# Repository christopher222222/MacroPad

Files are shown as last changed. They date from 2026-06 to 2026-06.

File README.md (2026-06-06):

# Full-Suite MacroPad
The Full-Suite MacroPad is a configurable macropad that incorporates Cherry MX key switches, a rotary encoder, and a 2" IPS screen that can display anything.
### Features

 - 2" IPS Display for displaying data and images (firmware support coming soon)
 - 12 Cherry MX Keyswitches
 - One Mechanical Rotary Encoder with Full Customization
 - 2000Mah Lipo Battery With Charging Circuit and Charge Sensing
 - Bluetooth Low Energy Wireless Connectivity With HID, Configuration, and Image Streaming Support (configuration and image streaming firmware support coming soon)
 - Full Low Latency NKRO (N-Key Rollover) Using MCP23017 I2C IO Expander
 - Optional Heatset Insets on the bottom of MacroPad for Custom Mounting

## CAD Model
This case uses an unconventional method of mounting by sliding from sides of the PCB to notches on the sides of the Front Case. After that, the case can now be fully assembled from 2 M3x5x4 heatset inserts and 2 M3x8 SHCS screws.
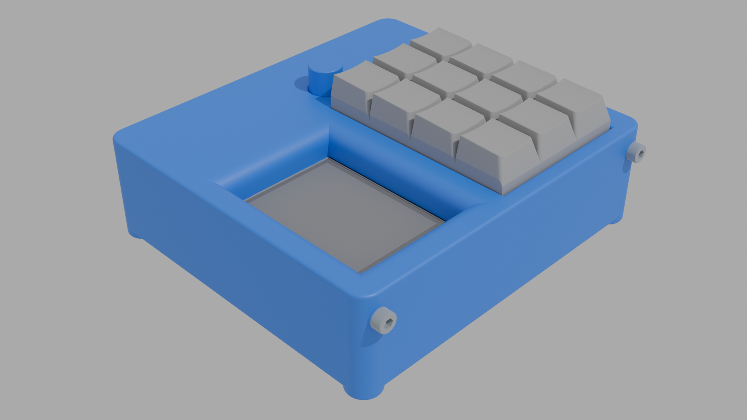
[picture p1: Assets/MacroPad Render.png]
MacroPad Render

Made in Onshape, Rendered in Blender.
## PCB and Schematic
The PCB and Schematic were both designed in EasyEDA Pro.
### Schematic
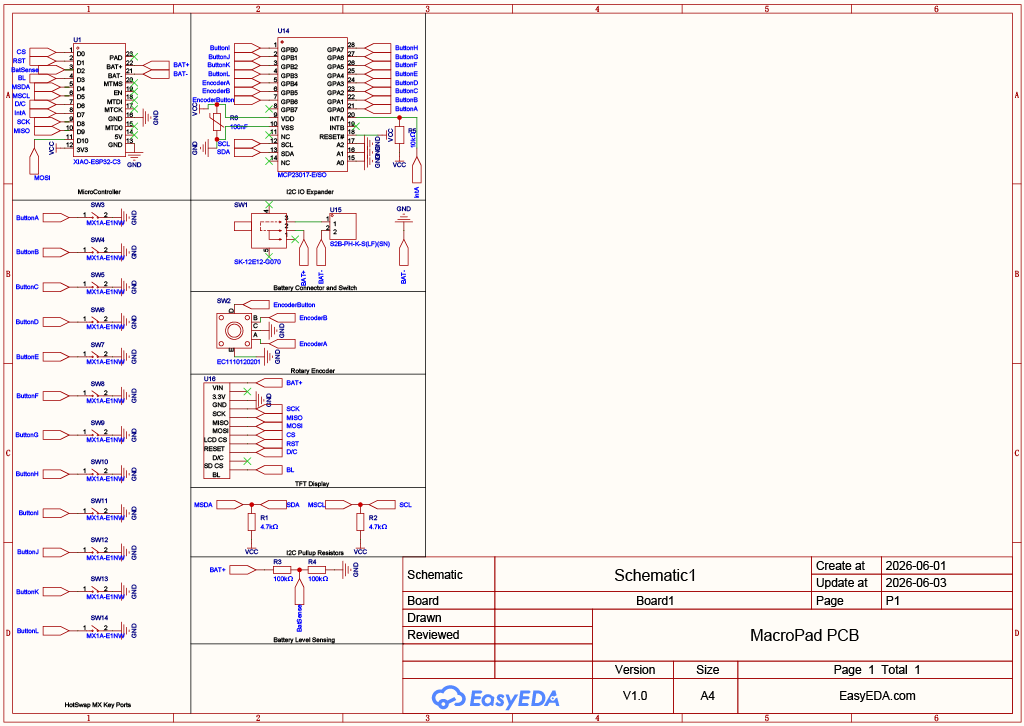
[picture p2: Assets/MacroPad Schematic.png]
MacroPad Schematic


### PCB
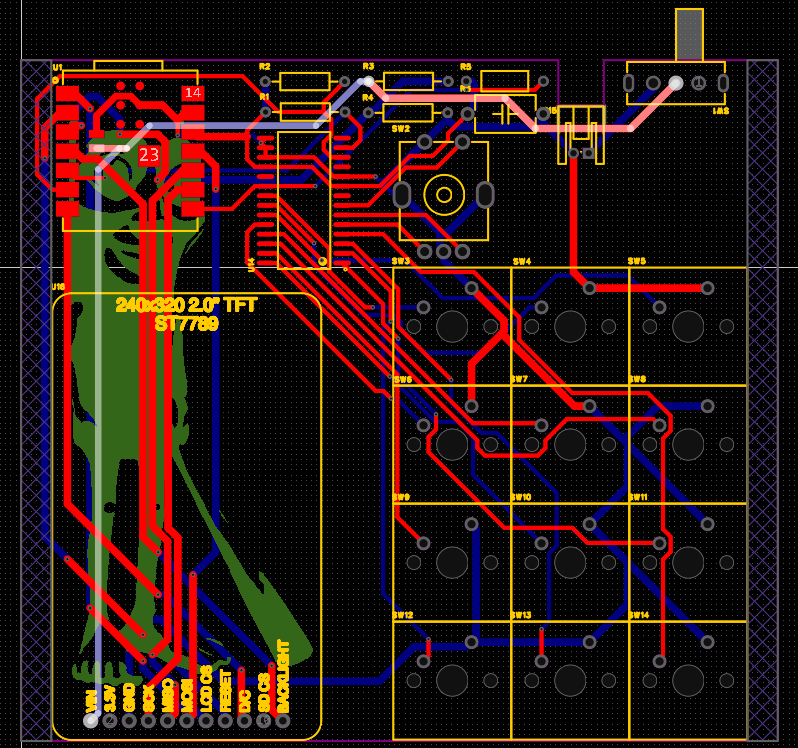
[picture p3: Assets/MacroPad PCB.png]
MacroPad PCB

(Tung for protection)
## Firmware
The firmware was an alternative approach to the regular QMK Firmware. It utilizes PlatformIO with the Arduino Framework and uses an object-oriented structure. The Bluetooth Low Energy data transfer including HID is handled via NimBLE as it is a very lightweight package. The data reading from the MCP23017 uses a common Adafruit library as it simplifies much of the code.
## Bill of Materials
|Item|Quantity|
|--|--|
| Seeed Xiao ESP32-C3 |1|
|MCP23017 I2C IO Expander|1|
|SK-12E12-G070 Slide Switch|1|
|S2B-PH-K-S 90° Angle JST PH Connector|1|
|Lithium Ion Battery - 2000Mah with JST PH Connector|1|
|Adafruit 2" IPS TFT Display|1|
|Cherry MX Keyswitch|12|
|DSA Keycaps Sanded to > 15.6mmx15.6mm|12|
|EC11 Mechanical Rotary Encoder|1|
|1/4W 100KΩ Resistor|2|
|1/4W 4.7KΩ Resistor|2|
|1/4W 10KΩ Resistor|1|
|16V 100nF Ceramic Capacitor|1|
|M3x5x4 Heatset Inserts|2-6|
|M3x8 SHCS Screw*|2|
|3D Printed Front Case|1|
|3D Printed Back Case|1|
|3D Printed Encoder Knob|1|
*SHCS screws can be swapped with BHCS

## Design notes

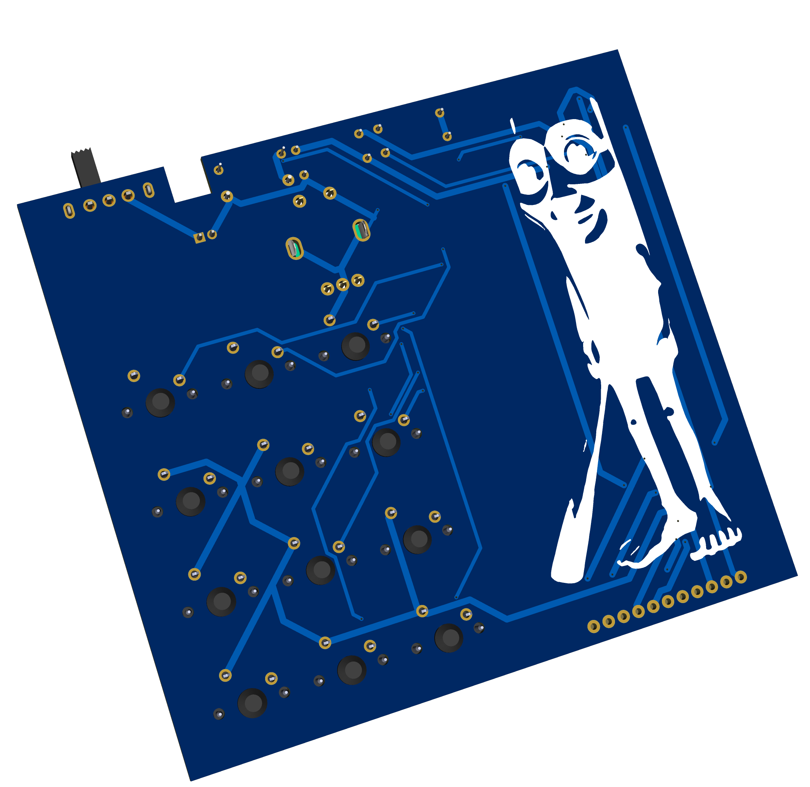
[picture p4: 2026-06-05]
PCB/3D/MacroPad_3D_Back.png

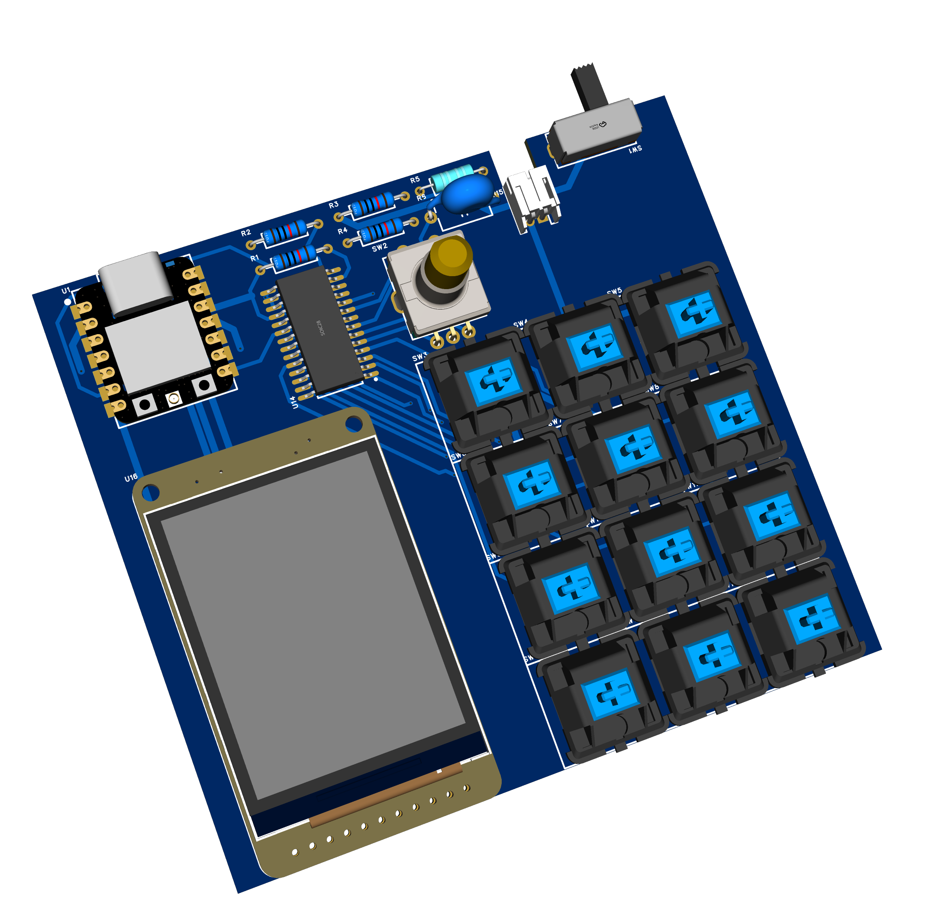
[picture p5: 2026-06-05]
PCB/3D/Macropad_3D_Front.png

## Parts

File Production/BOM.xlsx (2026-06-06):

Name | Quantity | Price w/o Shipping & Tax |  | Link | Chrismil122 Currently Owns/Owns Equivalent or Will Own After Recieveing Kit of Parts From HackClub (*)
Seeed XIAO ESP32-C3 | 1 | $4.99 |  | https://www.seeedstudio.com/Seeed-XIAO-ESP32C3-p-5431.html
MCP23017-E/SO | 1 | $1.87 |  | https://www.lcsc.com/product-detail/C47023.html
G-Switch SK-12E12-G070 | 5 | $0.67 | Only need 1 due to MOQ | https://www.lcsc.com/product-detail/C22448004.html
JST S2B-PH-K-S(LF)(SN) | 20 | $0.76 | Only need 1 due to MOQ | https://www.lcsc.com/product-detail/C173752.html
Lithium Ion Battery - 3.7V 2000mAh | 1 | $12.50 |  | https://www.adafruit.com/product/2011
2.0" Color IPS TFT Display | 1 | $19.95 |  | https://www.adafruit.com/product/4311
Cherry MX2A Black Linear Switches | 18 | $6.30 | Only need 12 due to MOQ | https://divinikey.com/collections/cherry-switches/products/cherry-mx2a-black-linear-switches | *
ALPSALPINE EC1110120201 | 1 | $6.43 |  | https://www.lcsc.com/product-detail/C470795.html | *
CF1/4W-100KΩ±5% T | 100 | $0.58 | Only need 2 due to MOQ | https://www.lcsc.com/product-detail/C120103.html | *
CF1/4W-4.7KΩ±5% T | 100 | $0.62 | Only need 2 due to MOQ | https://www.lcsc.com/product-detail/C120071.html | *
MF1/4W-10K±1%-ST52 | 100 | $0.69 | Only need 1 due to MOQ | https://www.lcsc.com/product-detail/C2903232.html | *
KEMET C315C104M5U5TA | 5 | $0.69 | Only need 1 due to MOQ | https://www.lcsc.com/product-detail/C1620210.html | *
1KG Blue Inland PETG+ | 1 | $15.99 |  | https://www.microcenter.com/product/626535/inland-175mm-petg-3d-printer-filament-1kg-(22-lbs)-spool-blue | *
Clear Keycaps for MX Compatible Switches - 12-pack | 1 | $6.95 |  | https://www.adafruit.com/product/5068 | *
PCB from JLCPCB with LeadFree HASL | 5 | $3.30 | Only need 1 due to MOQ | https://cart.jlcpcb.com/quote | *
Brass Heat Set Threaded Insert for Plastic - M3x5x4mm | 2 | $0.20 |  | https://kb-3d.com/store/inserts-fasteners-adhesives/278-brass-heat-set-threaded-insert-for-plastic-m3x5x4mm.html | *
M3X8 Socket Head Cap Machine Screws | 20 | $1.06 | Only need 2 due to MOQ | https://us.store.bambulab.com/products/m3-socket-head-cap-machine-screws-shcs-1?id=42334746607752 | *
220 Grit Sandpaper for sanding keys to size | 10 | $3.43 | Only need 1 due to MOQ | https://www.homedepot.com/p/DIABLO-1-3-Sheet-220-Grit-Hand-Sanding-Sheets-DCS323220S10G/313646817 | *

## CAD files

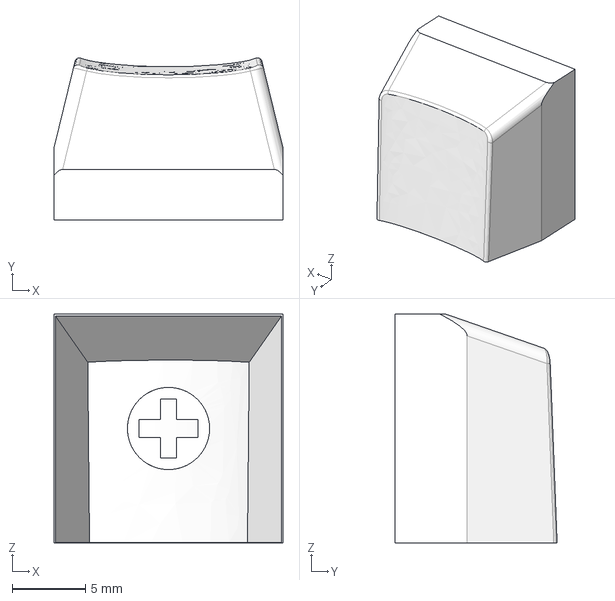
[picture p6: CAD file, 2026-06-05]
CAD/STEP/Cherry MX Keycap.step
15.6 x 11.1 x 15.6 mm

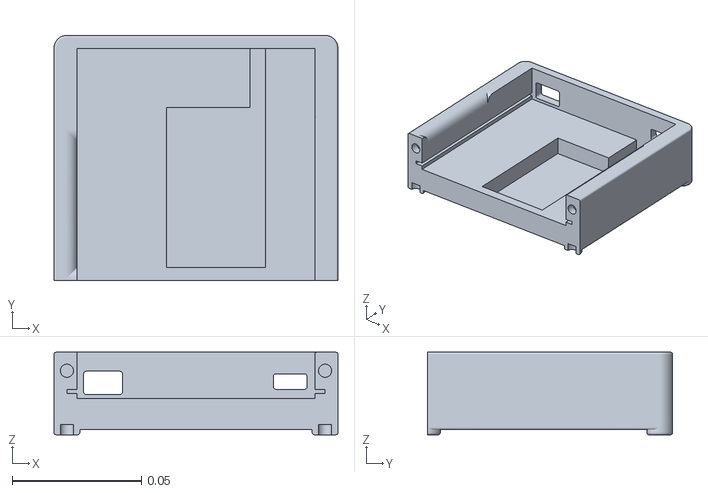
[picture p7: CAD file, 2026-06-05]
Production/Front Case.stl
0.11 x 0.095 x 0.032

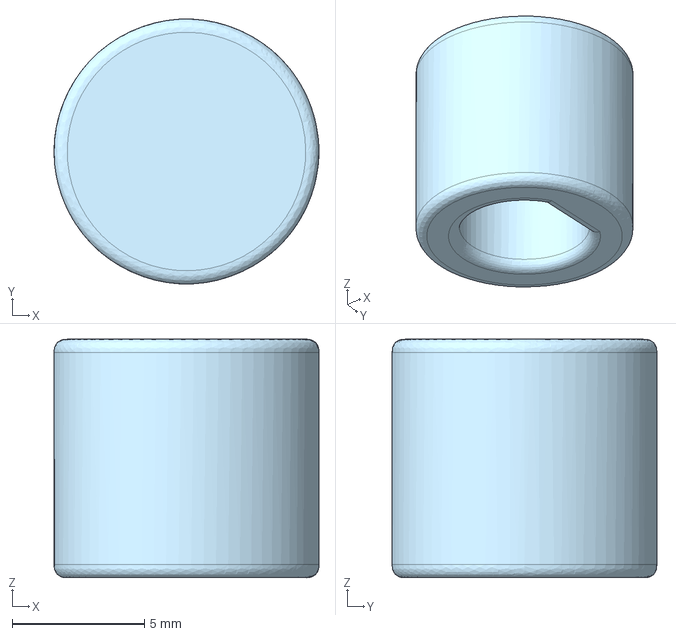
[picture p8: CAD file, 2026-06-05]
CAD/STEP/Encoder Knob.step
10.0 x 9.99 x 9.00 mm

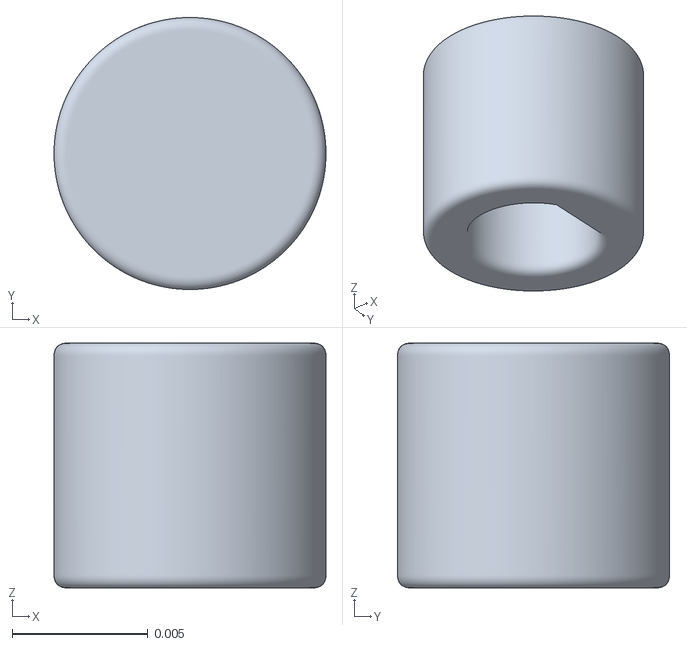
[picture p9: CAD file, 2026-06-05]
Production/Encoder Knob.stl
0.01 x 0.01 x 0.009

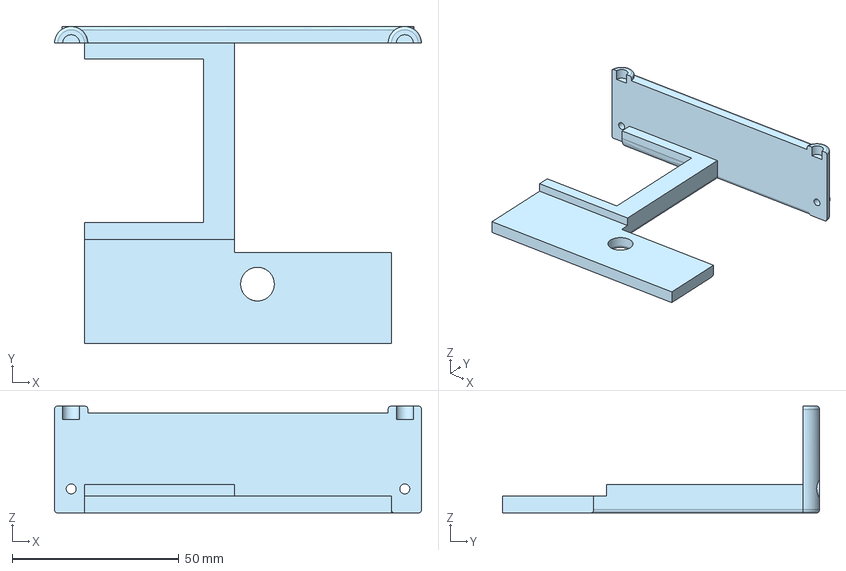
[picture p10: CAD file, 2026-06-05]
CAD/STEP/Back Case.step
110.0 x 95.0 x 32.0 mm

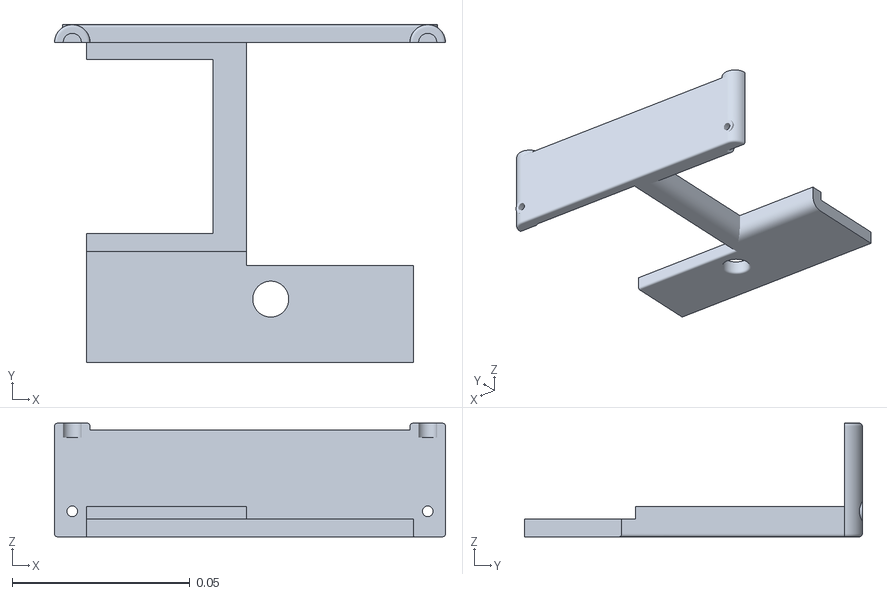
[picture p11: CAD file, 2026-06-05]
Production/Back Case.stl
0.11 x 0.095 x 0.032

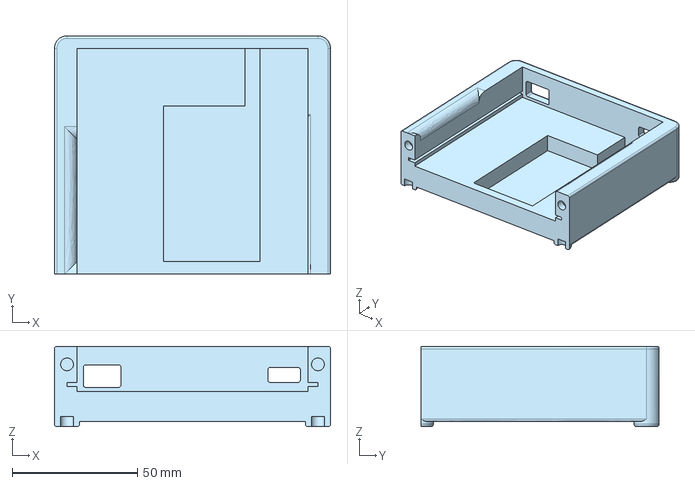
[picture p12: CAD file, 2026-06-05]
CAD/STEP/Front Case.step
110.0 x 95.0 x 32.0 mm

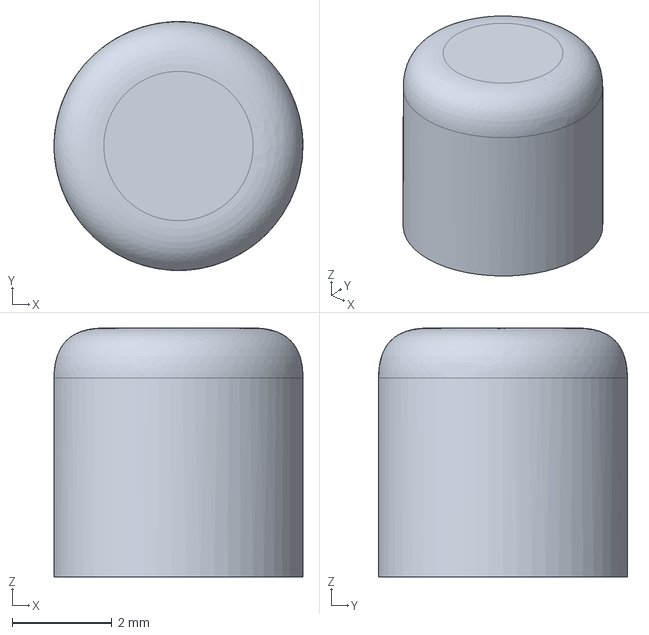
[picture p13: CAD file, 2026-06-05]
CAD/STEP/Rubber Foot.step
5.00 x 5.00 x 5.00 mm

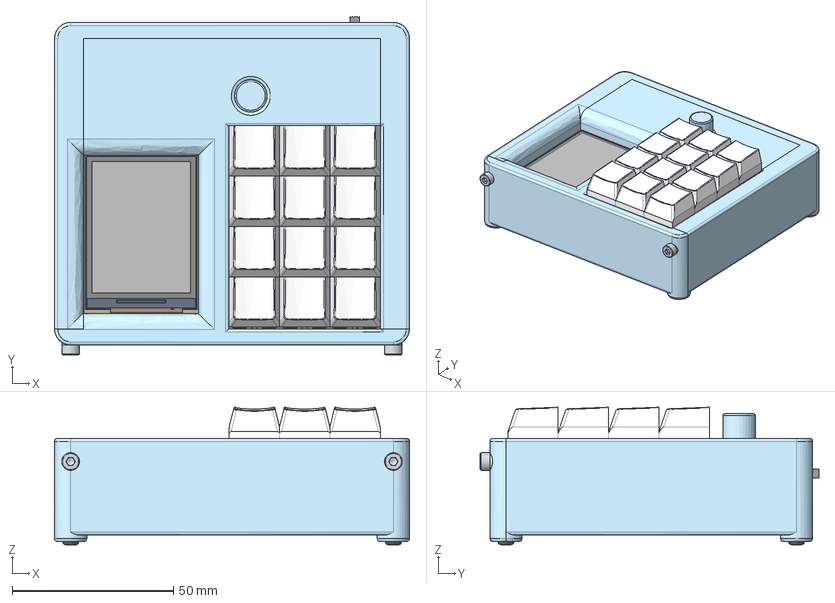
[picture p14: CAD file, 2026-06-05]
CAD/STEP/MacroPad.step
110.0 x 104.9 x 42.7 mm
SW-TH_MX1A-E1NW~libraries\MX1A-E1NW--3DModel-STEP-56544.STEP~yqiF_5 x 7
COMM-SMD_XIAO-ESP32-C3_1~libraries\Seeed Studio XIAO ESP32C3.step~yq iF x 73
Cherry MX Keycap x 12
CONN-TH_S2B-PH-K-S-LF-SN~CONN-TH_HR-PH2.0-WI-2P~yqiF x 14
SW-TH_EC111XXXX~SW-TH_EC111XXXX-L11.7-W13..0-H20.0-P2.5-LS14.5~yqiF x 18
SW-TH_MX1A-E1NW~libraries\MX1A-E1NW--3DModel-STEP-56544.STEP~yqiF_10 x 7
SW-TH_MX1A-E1NW~libraries\MX1A-E1NW--3DModel-STEP-56544.STEP~yqiF_8 x 7
RES-TH_BD2.3-L6.5-P10.50-D0.5~RES-TH_D2.3-L6.5-P10.50~yqiF_3
SOIC-28_L18.0-W7.5-P1.27-LS10.3-BL~SOIC-28_L17.9-W7.5-H2.7-LS10.3-P1. 27~yqiF x 22
SW-TH_MX1A-E1NW~libraries\MX1A-E1NW--3DModel-STEP-56544.STEP~yqiF_11 x 7
SW-TH_MX1A-E1NW~libraries\MX1A-E1NW--3DModel-STEP-56544.STEP~yqiF_9 x 7
SW-TH_MX1A-E1NW~libraries\MX1A-E1NW--3DModel-STEP-56544.STEP~yqiF_2 x 7
SW-TH_MX1A-E1NW~libraries\MX1A-E1NW--3DModel-STEP-56544.STEP~yqiF_4 x 7
Board~yqiF
display~libraries\4311 2in TFT IPS Display.step~yqiF x 15
SW-TH_MX1A-E1NW~libraries\MX1A-E1NW--3DModel-STEP-56544.STEP~yqiF_3 x 7
SW-TH_MX1A-E1NW~libraries\MX1A-E1NW--3DModel-STEP-56544.STEP~yqiF x 7
SW-TH_MX1A-E1NW~libraries\MX1A-E1NW--3DModel-STEP-56544.STEP~yqiF_7 x 7
SW-TH_MX1A-E1NW~libraries\MX1A-E1NW--3DModel-STEP-56544.STEP~yqiF_6 x 7
SW-TH_MX1A-E1NW~libraries\MX1A-E1NW--3DModel-STEP-56544.STEP~yqiF_1 x 7
CAP-TH_L8.0-W5.0-P10.00-D0.6~CAP-TH_BD8.0-W5.0-P10.0~yqiF
Rubber Foot x 4
RES-TH_BD2.3-L6.5-P10.50-D0.5~RES-TH_D2.3-L6.5-P10.50~yqiF
RES-TH_BD2.3-L6.5-P10.50-D0.5~RES-TH_D2.3-L6.5-P10.50~yqiF_1
Hex socket head cap screw M3x0.50 x 8 x 2
SW-TH_SK-12E12-G070~SW-TH_SK-12E12-G070~yqiF x 2
RES-TH_BD2.7-L6.2-P10.20-D0.4~RES-TH_BD2.7-L6.2-P10.20-D0.4~yqiF
Front Case
Back Case
RES-TH_BD2.3-L6.5-P10.50-D0.5~RES-TH_D2.3-L6.5-P10.50~yqiF_2
Encoder Knob

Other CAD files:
CAD/STL/Cherry MX Keycap.stl
CAD/STL/Rubber Foot.stl

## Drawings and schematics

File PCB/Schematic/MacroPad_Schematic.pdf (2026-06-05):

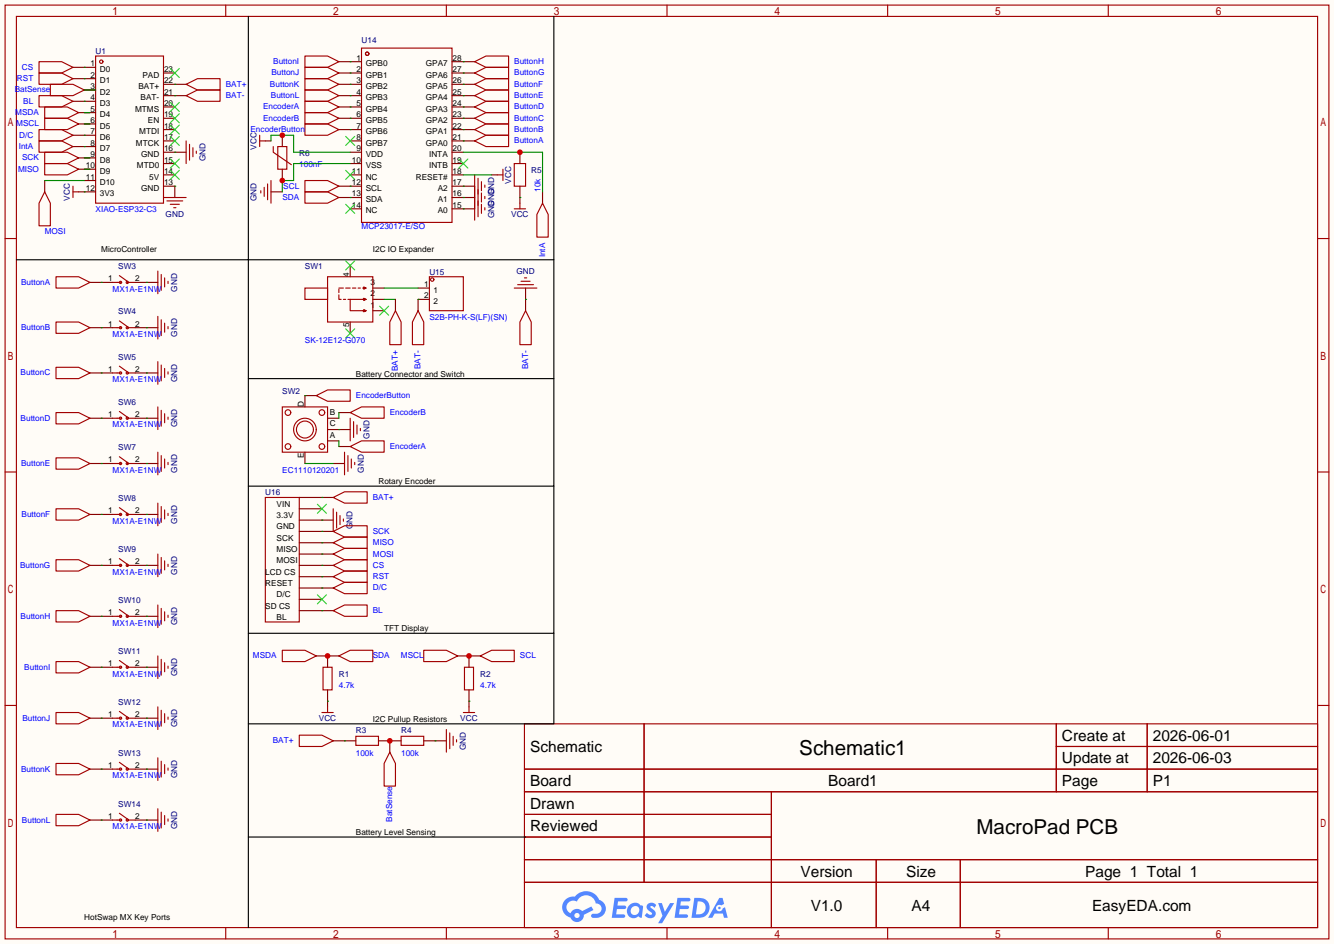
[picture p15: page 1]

GND GND GND GND GND GND

Battery Connector and Switch

Schematic | Schematic1 | Create at | 2026-06-01

Update at | 2026-06-03

Board | Board1 | Page | P1
Drawn | | MacroPad PCB
Reviewed

Version | Size | Page 1 Total 1
V1.0 | A4 | EasyEDA.com

HotSwap MX Key Ports

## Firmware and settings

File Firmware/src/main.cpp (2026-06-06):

#include <Arduino.h>
#include "Input.h"
#include "HID.h"

extern volatile bool mcpActionRequired;

static uint32_t lastBatteryUpdate = 0;

extern InputClass input;
extern HIDClass hid;

void setup() {
  input.init();
  hid.init("MacroPad");
}

void loop() {
  if (mcpActionRequired) {
    mcpActionRequired = false;

    InputData packet = input.readHardware();

    hid.sendKeys(packet.keys);

    if (packet.encoderTurned) {
      hid.sendDialTurn(packet.encoderClockwise);
    }

    if (packet.encoderButtonChanged) {
      hid.sendEncoderButton(packet.encoderButtonPressed);
    }
  }

if (millis() - lastBatteryUpdate > 60000) { 
    hid.updateBatteryPercentage(input.getBatteryLevel());
    lastBatteryUpdate = millis();
}
}

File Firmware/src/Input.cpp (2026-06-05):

#include "Input.h"

Adafruit_MCP23X17 mcp;
InputClass input;

volatile bool mcpActionRequired = false;

ICACHE_RAM_ATTR void handleMcpInterrupt() { mcpActionRequired = true; }


void InputClass::init(){
    mcp.begin_I2C(0x20);

    pinMode(INTERRUPT_PIN, INPUT);
    pinMode(BATTERYSENSE_PIN, INPUT);
    attachInterrupt(digitalPinToInterrupt(INTERRUPT_PIN), handleMcpInterrupt, FALLING);

    mcp.setupInterrupts(true, false, LOW);

    for (uint16_t i = 0; i <= 14; i++){
        mcp.pinMode(i, INPUT_PULLUP);
        mcp.setupInterruptPin(i, CHANGE);
    }

    _lastEncoderA = mcp.digitalRead(12);
    _lastEncoderButton = (mcp.digitalRead(14) == LOW);
    mcp.clearInterrupts();
}

InputData InputClass::readHardware() {
    InputData data{};

    uint32_t now = millis();

    if (now - _lastDebounceTime < 25){
        mcp.clearInterrupts();
        return data;
    }
    _lastDebounceTime = now;

    for (uint16_t i = 0; i < 12; i++) {
        _keys[i] = (mcp.digitalRead(i) == LOW);
        data.keys[i] = _keys[i];
    }
    
    bool currentA = mcp.digitalRead(12);
    bool currentB = mcp.digitalRead(13);

    if(currentA != _lastEncoderA){
        data.encoderTurned = true;
        data.encoderClockwise = (currentA == currentB);
    }
    _lastEncoderA = currentA;

    bool currentBtn = (mcp.digitalRead(14) == LOW);
    if (currentBtn != _lastEncoderButton) {
        data.encoderButtonChanged = true;
        data.encoderButtonPressed = currentBtn;
    }
    _lastEncoderButton = currentBtn;

    mcp.clearInterrupts();
    return data;
}

int InputClass::getBatteryLevel(){
    int mv = analogReadMilliVolts(BATTERYSENSE_PIN);
    if (mv < 500) {
        return 100;
    } else {
        return constrain(map((mv * 2), 3300, 4200, 0, 100), 0, 100);
    }
}

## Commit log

2026-06-05 First Commit
    This is the inaugural commit of the MacroPad. This first commit has taken me many hours and I hope for this project to thrive.
    [Back Case.step, Back Case.stl, Cherry MX Keycap.step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]
2026-06-06 Created extensive BOM
    [BOM.xlsx]
2026-06-06 Optimized Layout for HackPad Submission
    [Back Case.stl, Encoder Knob.stl, Front Case.stl]
2026-06-07 Added BOM to Production Folder
    [BOM.xlsx]
